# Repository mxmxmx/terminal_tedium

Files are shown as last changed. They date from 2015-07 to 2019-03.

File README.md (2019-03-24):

terminal_tedium
===============

My image

raspberry pi 2 / pi 3 / zero (W) / pi a+ / b+  eurorack stereo codec (wm8731) breakout board *

- 4x digital inputs (> 100k input impedance; threshold > 3V)
- 2x digital outputs (~ 6V )
- 6x CV inputs (100k input impedance; 12 bit, +/- 5V range)
- 2x audio outputs (10VPP, 16bit / 48kHz)
- 2x audio inputs (50k input impedance, 16bit / 48kHz)

build info, see here: https://github.com/mxmxmx/terminal_tedium/wiki

[PCBs/panels](https://pushermanproductions.com/?s=terminal&post_type=product)

## places to find Pd patches for Terminal Tedium
Here are a few places where you can find Pd patches that others have written for the Terminal Tedium:

- [Old Man Fury's Github repos](https://github.com/oldmanfury)
- [Wilsontr's Github repo](https://github.com/wilsontr/tt-patches)
- [j-p-higgins' Github repo](https://github.com/j-p-higgins/jh.tt)
- [North Coast Modular Collective's Github repo](https://github.com/NorthCoastModularCollective/Terminal-Tedium-Pd-Patches)
- [JMC64 Patches](https://github.com/JMC64/Terminal-Tedium-)

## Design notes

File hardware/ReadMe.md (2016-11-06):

# this folder contains various CAM files and design resources.

- ### the `gerbers` folder is … where the gerber files can be found.

- the remaining stuff is mostly about panels, ie layout + dimensions:

  - .fpd (for use with front panel express / schaeffer)
  - .svg and .pdf (for use with whatever)
  - .fzz is another panel design. you'll need fritzing to edit it, adjust pot-sizes, graphics, etc

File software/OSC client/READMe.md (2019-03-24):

# (primitive) OSC / UDP client

- note: as is, the client works with the wm8731 version only.

- still needs adjusting port # and IP address *manually* (in `int main(void)`)

- compile with: 

`gcc *.c -Werror -lwiringPi -std=gnu99 -O2 -g -o tedium_osc` 

- run with:

`sudo ./tedium_osc`

- adc values 0-5 are sent as an OSC bundle (range = `0 (min) - 4000 (max)`): 

`/adc0 value, /adc1 value, /adc2 value ... `

- button presses (short, long) and triggers are sent as individual OSC messages (`1` or `0`), namely:

`/trigger1 value`
`/trigger2 value`
`/trigger3 value`
`/trigger4 value`

`/button1 value`
`/button2 value`
`/button3 value`

`/button1_long value`
`/button2_long value`
`/button3_long value`

- edit main.c to customize the messages.

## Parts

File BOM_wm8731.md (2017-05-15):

# BOM for terminal tedium IO 

### resistors 0603:

| value | # | note |
| --- | ---: | --- |
| 200R | 2x | |
| 220R | 4x | filter bead; mouser # 81-BLM18BB221SN1D |
| 510R | 4x | |
|1k | 4x | |
| 4k7 | 2x | |					
| 5k6 | 2x | | 		 
| 10k | 2x | | 				
| 24k9 | 12x | |				
| 27k | 2x | | 					
| 33k | 5x | | 			
| 47k | 5x | | 
| 49k9 | 2x | (or use 47k) |
| 100k | 14x |  |			
| LED resistors | 2x | (for the 3mm LEDs) (†) |

- (†) best to use **ultrabright** LEDs, and correspondingly large resistor values (to taste) (V+ = 3.3v); for the illuminated tact switch, 200R works ok (as per BOM)

### caps 0603 (25v or better):

| value | # | note |
| --- | ---: | --- |
| 18-20p | 6x | NP0/C0G |
| 10n | 7x | NP0/C0G |	 
| 100n | 14x | MLCC | 
| 470n | 3x | MLCC |
| 1uF  | 2x | MLCC (may be 0805) |
| 10uF | 2x | MLCC (may be 0805) |

### electrolytic caps, SMD:

| value | # | note |
| --- | ---: | --- |
| 10uF | 5x | 16V or better; diameter < 5.3mm; e.g. mouser # 647-UUQ1E100MCL1GB |
| 33uF | 3x | 25V or better; diameter < 8mm |

### ICs/semis/etc:

| what | # | package | note |
| --- | ---: | --- | --- |
| WM8731 | 1 x | TSSOP-28 | mouser # 238-WM8731SEDS/V |
| MCP3208 | 1x | SOIC16 | mouser # 579-MCP3208CISL |
| TL072 | 3x | SOIC8 | see note (†) |
| MCP6002 | 1x | SOIC8 | mouser # 579-MCP6002T-I/SN |
| MCP6004 | 1x | SOIC14 | mouser # 579-MCP6004T-I/SL |
| MMBT3904 | 4x | SOT-23 | mouser # 512-MMBT3904 |
| SM5817PL-TP | 3x | SOD-123FL | mouser # 833-SM5817PL-TP |
| ADP150 | 1x | TSOT | 3v3 regulator; mouser # 584-ADP150AUJZ-3.3R7 |
| LM4040-2v5 | 1x | SOT-23 | - |
| LM4040-10v | 1x | SOT-23 | - |

- (†) two of the TL072s are in the audio path — if you’d like, use something better for the output stage.

### through-hole parts:

| what | # | package | note |
| --- | ---: | --- | --- |
| 12.288 MHz crystal | 1x | HC-49/S |  low profile |
| electrolytic capacitor, **10uF** | 2x | 2.5mm | 16V+ (for DC block / **audio** output) |
| inductance, 10uH | 1x | - | e.g. mouser # 542-78F100-RC |
| RECOM 785.0 1.0 | 1x | - | mouser # 919-R-785.0-1.0 (†) |
| 3mm LEDs | 2x | - | (use ultra-bright) |

- (†) the 500 ma version should do for models a+, b+; pi 2 needs 1.0, it looks like; as a cheaper/less efficient solution, use a 7805. if planning to power the raspberry via usb (= 5v disconnected! or no 5V regulator soldered), no such $ regulator is needed, of course.

### misc:

| what | # | note |
| --- | ---: | --- |
| jacks | 16x | thonkiconn/kobiconn |
| potentiometers | 6x | 9mm vertical, 10k**B** |
| tact switches | 2x | multimecs 5E/5G series; mouser # 642-5GTH935 |
| illum. tact switch | 1x | ditto; e.g. mouser # 642-5GTH93542 (= YELLOW) |
| caps, black | 2x | mouser # 642-1SS09-15.0, or 642-1SS09-16.0 |
| caps, transparent | 1x | mouser # 642-1IS11-15.0, or 642-1IS11-16.0 |
| 2-pin header, male | 1x | RM2.54 (+ little jumper plastic thingie to match (= the 5V power jumper)|
| raspberry GPIO socket, 2x20 | 1x | RM2.54, extra-tall female socket for RPI (†) |
| spacer/standoff (M3) | 2x | to match height of the 2x20 socket/header (c. 20mm for pi B+, pi 2, pi 3) |

- (†) or four of [these](http://www.taydaelectronics.com/connectors-sockets/stackable-headers/stackable-header-10-pins-2-54mm.html), for example, will do; if planning to use model A+ or zero, the socket doesn't have to be as tall.

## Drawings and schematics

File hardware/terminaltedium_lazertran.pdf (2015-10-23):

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

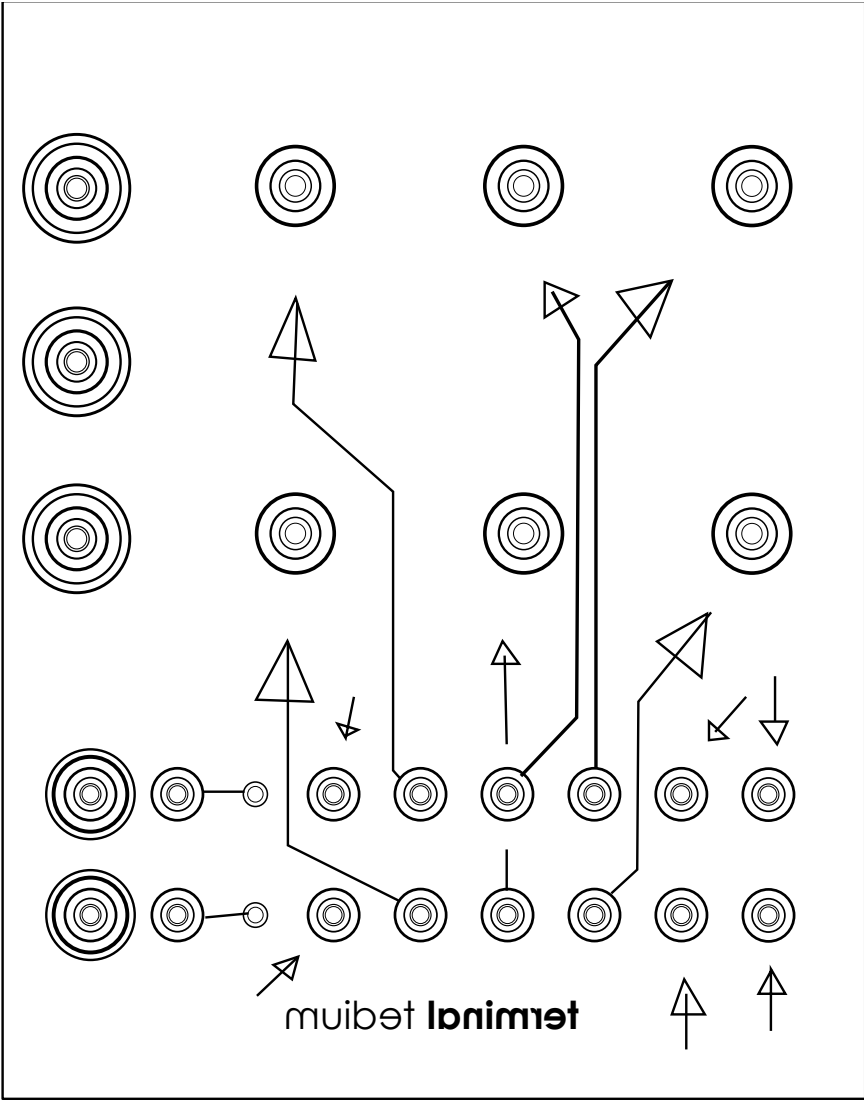
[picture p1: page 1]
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

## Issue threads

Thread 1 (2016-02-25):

RPI 2 problems with wm8731

Shibonja, 2016-02-25:
Hi,

Nice work you have done with the sound mixer. Can I ask you which version of raspbian you are using. I downloaded Raspbian Jessie (kernel version 4.1.18-v7+) and can't get my wm8731 working.
I am getting these errors in dmesg:
```bash
[    6.100440]snd-rpi-proto sound: ASoC: CPU DAI (null) not registered
[    6.100462] snd-rpi-proto sound: snd_soc_register_card() failed: -517
[    6.100963] snd-rpi-proto sound: ASoC: CPU DAI (null) not registered
[    6.100989] snd-rpi-proto sound: snd_soc_register_card() failed: -517
[    6.102795] bcm2708_i2c 3f804000.i2c: BSC1 Controller at 0x3f804000 (irq 79) (baudrate 100000)
[    6.103079] snd-rpi-proto sound: ASoC: CPU DAI (null) not registered
[    6.103091] snd-rpi-proto sound: snd_soc_register_card() failed: -517
[    6.105641] snd-rpi-proto sound: ASoC: CODEC DAI wm8731-hifi not registered
[    6.105654] snd-rpi-proto sound: snd_soc_register_card() failed: -517
```
Regards, Haris

Shibonja, 2016-02-25:
Hi, I got playback working.  But sound recording doesn't work, have you experience with sound recording.

mxmxmx, 2016-02-25:
Hi Haris,

I haven't done any nice work with the sound mixer (?), but observing [this](https://github.com/mxmxmx/terminal_tedium/wiki/DAC#3-amixer) should be enough to get the inputs working.

mxmxmx, 2016-02-25:
As this seems to be about mikroelektronika boards, not terminal tedium, I'm closing this Issue.

Closed 2016-02-25.

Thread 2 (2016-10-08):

DC Coupled Audio Output to use as CV?

bsom, 2016-10-08:
It is stated here: https://github.com/mxmxmx/terminal_tedium/wiki/wm8731
that the audio outputs are "simple inverting amplifier with ~ 4.75x gain; outputs are DC blocked".

Is there a modification/edit/hack that could be done so that the audio outs are actually able to produce something closer to DC-coupled CV?

synthbytes, 2016-10-08:
DC blocked means there is a capacitor terminating the output and will only let AC pass. To allow DC you'd remove the cap.

bsom, 2016-10-08:
I understand that, but without a schematic, it is hard for me to be sure I am removing the correct part.

mxmxmx, 2016-10-09:
... the link above comes with the relevant schematic snippet (?) --https://github.com/mxmxmx/terminal_tedium/wiki/wm8731#output-stage

or what else would you need ? fwiw, the caps in question are the through-hole ones on the top side of the board.

bsom, 2016-10-11:
Thanks for the hint about the through-hole electrolytic caps.

Closed 2016-10-11.

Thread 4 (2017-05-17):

PiCore requires wiringPi-Dev to be installed to compile Externals

bsom, 2017-05-17:
In order to compile the Externals on PiCore, wiringPi-Dev is required.  It contains the headers for wiringPi.  I don't know if this is true for 'regular' RaspPi distributions, but I needed to do it with PiCore 8.x and 9.0.

mxmxmx, 2017-05-17:
ok, thanks -- added it to the how-to (which i guess could need an update)

bsom, 2017-05-18:
I'm about to construct an additional T_T using piCore 9.0.  I'll make notes about where the instructions for piCore need updating and submit another issue with potential changes.

mxmxmx, 2017-05-18:
cool, that would be great ("could need an update" was more like a note to myself though!)

Closed 2017-05-17.

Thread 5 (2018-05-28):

Schematic files

wraybowling, 2018-05-28:
It's already noted in the hardware readmme that schematics are absent. Could be solved. I'm starting a KiCAD schematic on my fork, but consider myself by no means an expert. Help is welcome

mxmxmx, 2018-05-30:
hey
you probably can save your time ... Raffael / @seismicindustries has redrawn the board, with OLED(s) added. not entirely sure what the status is, but it's almost there, i think.

bsom, 2018-05-30:
I only see the O_c on @seismicindustries.  Has he not published it yet or are you confusing the O_c with the terminal_tedium?

mxmxmx, 2018-05-30:
not published yet

bsom, 2018-05-30:
Well, now I’m excited to see what became up with!

seismicindustries, 2018-05-30:
now published. but untested so far.
https://github.com/seismicindustries/TT

wraybowling, 2018-06-28:
@seismicindustries Firstly THANK YOU. I'm still a super beginner with electronics design and KiCAD so that was extremely useful.

Second, here's the BOM converted to Octopart https://octopart.com/bom-tool/v96smgng

Third, @mxmxmx, this is a great start to getting the hardware updated on your repo. Still think that we should do that.

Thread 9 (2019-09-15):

compatible with raspberry pi 4 B?

michaelpalumbo, 2019-09-15:
Hi there, exciting project!

Is this by any chance compatible with the newer raspberry pi model 4 B?

Thanks!

mxmxmx, 2019-09-16:
in terms of pin usage/signals, yes ("Complete compatibility with earlier Raspberry Pi products"). in terms of power requirements, pi 4 may begin stretching things a little (RECOM 785.0 1.0 = 1.0A; they recommend using 3.0A). that said, you can just power the pi 4 separately, simply remove the [jumper](https://github.com/mxmxmx/terminal_tedium/wiki/wm8731#power) to disconnect the SoC from the onboard 5V.

michaelpalumbo, 2019-09-18:
@mxmxmx well thats rad! and also kinda cool that the TT wouldn't take up a power port from my euro supply. thanks!

Closed 2019-09-18.

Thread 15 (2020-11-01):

100K Resistors quantity

RiccardoRics, 2020-11-01:
Hi there, on the BOM file are reported 14x 100K resistors, but on the REV.1 board I see 18x 100K.
Is that a typo into the BOM?

2x near the 072
4x near the MCP6002
8x near the MCP6004
4x near the GPIO 04-14-17-27

I've downloaded the gerber zip and by opening the "terminal_tedium_io_rev2016_pnp.txt" file I searched for 100K and found effectively 18x 100K resistors elements.

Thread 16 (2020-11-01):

10nF quantity

RiccardoRics, 2020-11-01:
Hi there, on the BOM file are reported 7x 10nF caps, but on the REV.1 board I see 1x 10nF and 6x 1nF.
Is that a typo into the BOM?

1x 10nF near the 072
2x 1nF near the MCP6002
4x 1nF near the MCP6004

Into the "terminal_tedium_io_rev2016_pnp.txt" file I searched for 10nF and found effectively 7x 10nF caps elements but no 1nF elements.

RiccardoRics, 2020-11-01:
Ok, got the tip on the building wiki page:

"you can follow the values indicated on the pcb. no special precautions required. except, ideally use 10nF caps (NP0) where it says 1nF (around the MCP6002s). (silkscreen fixed in revision 1.1)"

Closed 2020-11-01.

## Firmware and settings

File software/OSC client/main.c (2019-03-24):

/*
*
*   terminal tedium / OSC client (UDP)
*
*     
*   - TD: gate outputs (?); make nicer. etc (pigpio?)
*   - TD: make more userfriendly, pass IP and port as arguments, etc.
*
*
*   compile with: gcc *.c -Werror -lwiringPi -std=gnu99 -O2 -g -o tedium_osc 
*/

#define DEFAULT_SOURCE

#include <stdio.h>
#include <string.h>
#include <stdlib.h>
#include <arpa/inet.h>
#include <sys/socket.h>
#include <fcntl.h>
#include <time.h>
#include <unistd.h>
#include <sys/time.h>  

#include <wiringPi.h>
#include <wiringPiSPI.h>

#include "tinyosc.h"

const uint16_t BUFLEN = 1024;
const uint64_t NOW = 1L;
const uint32_t TIMEOUT = 1000;    // sleep (in us)
const uint32_t TIMEOUT_T = 10;    // short time out (for OSC off messages) (triggers) // 10 * TIMEOUT (us)

#define ADC_SPI_CHANNEL 1
#define ADC_SPI_SPEED 4000000
#define ADC_NUM_CHANNELS 6
#define ADC_NUM ADC_NUM_CHANNELS-1
#define RESOLUTION 4095
#define DEADBAND 2
#define SCALE 4000
#define SCALE_INV 1.0f/(float)SCALE

// GPIO : 

#define B1 23
#define B2 25
#define B3 24
#define LED 26
#define TR1 4
#define TR2 17
#define TR3 14
#define TR4 27
#define GATE1 16
#define GATE2 12

#define _MUTEX 0

void die(char *s)
{
    perror(s);
    exit(1);
}

uint16_t adc[ADC_NUM_CHANNELS]; // adc values


/*  interrupt flags etc:  */

static volatile uint8_t TR1_flag = 0;
static volatile uint8_t TR2_flag = 0;
static volatile uint8_t TR3_flag = 0;
static volatile uint8_t TR4_flag = 0;
static volatile uint8_t B1_flag  = 0;
static volatile uint8_t B2_flag  = 0;
static volatile uint8_t B3_flag  = 0;

void Interrupt_TR1 (void) { TR1_flag = 1; }
void Interrupt_TR2 (void) { TR2_flag = 1; }
void Interrupt_TR3 (void) { TR3_flag = 1; }
void Interrupt_TR4 (void) { TR4_flag = 1; }
void Interrupt_B1  (void) { B1_flag  = 1; }
void Interrupt_B2  (void) { B2_flag  = 1; }
void Interrupt_B3  (void) { B3_flag  = 1; }

// flags and counters for on/off messages:

uint8_t TR1_OFF = 0; 
uint8_t TR2_OFF = 0; 
uint8_t TR3_OFF = 0; 
uint8_t TR4_OFF = 0; 
uint16_t _wait_TR1, _wait_TR2, _wait_TR3, _wait_TR4; 

/* 

mcp3208 : return 1 if we need to send OSC, 0 otherwise

*/


uint16_t readADC(int _channel, uint16_t *adc_val){ 

      uint8_t spi_data[3];
      uint16_t result, tmp = *(adc_val + _channel); // previous.

      spi_data[0] = 0x06 | (_channel>>2) & 0x01;    // single ended
      spi_data[1] = _channel<<6;
      spi_data[2] = 0x00;

      wiringPiSPIDataRW(ADC_SPI_CHANNEL, spi_data, 3);

      // invert + limit result: 
      result = SCALE - (((spi_data[1] & 0x0f) << 8) | spi_data[2]);
      result = result > RESOLUTION ? 0 : result;  
      
      if ( (result - tmp) > DEADBAND || (tmp - result) > DEADBAND ) { 
        *(adc_val + _channel) = result ;
        return 1;
      }
      else {
        *(adc_val + _channel)  = tmp;
        return 0;
      }
}


///  buttons: 


enum button_states 
{
  OK,
  PRESSED,
  SHORT_PRESS,
  LONG_PRESS,
  SEND_OFF_MSG,
  SEND_OFF_MSG_L
};

typedef struct buttons
{
   uint8_t _pin;
   uint8_t _state;
   uint8_t _OSC_state;
   uint16_t _cnt;

} buttons;

buttons *button1, *button2, *button3;


void init_buttons() {

  button1 = (buttons*)malloc(sizeof(buttons));
  button2 = (buttons*)malloc(sizeof(buttons));
  button3 = (buttons*)malloc(sizeof(buttons));

  button1->_pin = B1;
  button1->_state = OK;
  button1->_OSC_state = OK;
  button1->_cnt = 0;

  button2->_pin = B2;
  button2->_state = OK;
  button2->_OSC_state = OK;
  button2->_cnt = 0;

  button3->_pin = B3;
  button3->_state = OK;
  button3->_OSC_state = OK;
  button3->_cnt = 0;

}

void check_buttons(struct buttons* _b, int time_out)
{

  if (_b->_state == PRESSED) {

        uint8_t _s = digitalRead(_b->_pin);
        if (!_s) _b->_cnt++;
        else if (_s && _b->_cnt < time_out)  _b->_state = SHORT_PRESS;
        else if (_s && _b->_cnt >= time_out) _b->_state = LONG_PRESS;

  }
  else if (_b->_state > PRESSED) { 

        piLock (_MUTEX);
          _b->_OSC_state = _b->_state;
        piUnlock (_MUTEX);  
        // reset
        _b->_state = OK;
        _b->_cnt = 0;
  }
}

///////////////////

PI_THREAD (handle_GPIO)
{

  uint16_t time_out = 125; // wait until longpress
  uint32_t _sleep = TIMEOUT*6;

  init_buttons();

  while(1) {

     usleep(_sleep);

     if (B1_flag && button1->_state == OK) { 

        B1_flag =  0;
        button1->_state = PRESSED;
     }

     if (B2_flag && button2->_state == OK) { 

        B2_flag =  0;
        button2->_state = PRESSED;
     }

     if (B3_flag && button3->_state == OK) { 

        B3_flag =  0;
        button3->_state = PRESSED;
     }

     check_buttons(button1, time_out);
     check_buttons(button2, time_out);
     check_buttons(button3, time_out);
  }
}

/* --------------------------------------------------------- */

int main(void)
{
    struct sockaddr_in _serv;
    int s, i, slen = sizeof(_serv);
    char buf[BUFLEN];
    int port = 9000;
    char *ip = "127.0.0.1"; 

    memset(adc, 0, ADC_NUM_CHANNELS);

    // open socket : 
    if ((s=socket(AF_INET, SOCK_DGRAM, IPPROTO_UDP)) == -1) die("socket");
    
    memset((char *) &_serv, 0, sizeof(_serv));
    _serv.sin_family = AF_INET;
    _serv.sin_port = htons(port);
    _serv.sin_addr.s_addr =  inet_addr(ip);

    // OSC bundle
    tosc_bundle bundle;

    // setup SPI
    wiringPiSetupGpio();
    wiringPiSPISetup(ADC_SPI_CHANNEL, ADC_SPI_SPEED);

    // pull ups:
    pinMode(B1, INPUT);
    pullUpDnControl(B1, PUD_UP);
    pinMode(B2, INPUT);
    pullUpDnControl(B2, PUD_UP);
    pinMode(B3, INPUT);
    pullUpDnControl(B3, PUD_UP);

    pinMode(TR1, INPUT);
    pullUpDnControl(TR1, PUD_UP);
    pinMode(TR2, INPUT);
    pullUpDnControl(TR2, PUD_UP);
    pinMode(TR3, INPUT);
    pullUpDnControl(TR3, PUD_UP);
    pinMode(TR4, INPUT);
    pullUpDnControl(TR4, PUD_UP);

    // LED + gate outputs (??) (what should those do?)
    pinMode(LED, OUTPUT);
    pinMode(GATE1, OUTPUT);
    pinMode(GATE2, OUTPUT);

    // interrupt, trigger inputs: 
    wiringPiISR (TR1, INT_EDGE_FALLING, &Interrupt_TR1) ;
    wiringPiISR (TR2, INT_EDGE_FALLING, &Interrupt_TR2) ;
    wiringPiISR (TR3, INT_EDGE_FALLING, &Interrupt_TR3) ;
    wiringPiISR (TR4, INT_EDGE_FALLING, &Interrupt_TR4) ;
    
    // interrupt, buttons: 
    wiringPiISR (B1, INT_EDGE_FALLING, &Interrupt_B1)  ;
    wiringPiISR (B2, INT_EDGE_FALLING, &Interrupt_B2)  ; 
    wiringPiISR (B3, INT_EDGE_FALLING, &Interrupt_B3)  ; 

    // flags
    int _cnt = 0, _send = 0, toggle = 0;

    // thread to handle buttons
    piThreadCreate (handle_GPIO);

    // main action is happening here (..)
     while(1)
    {
            usleep(TIMEOUT);
            // get adc value
            _send += readADC(_cnt, adc);
            // do we need to send an OSC bundle? 
            if (_cnt == ADC_NUM && _send) {
              
                  // construct OSC bundle:
                  tosc_writeBundle(&bundle, NOW, buf, BUFLEN);
                  tosc_writeNextMessage(&bundle, "/adc0", "f", (float)adc[0] * SCALE_INV);
                  tosc_writeNextMessage(&bundle, "/adc1", "f", (float)adc[1] * SCALE_INV);
                  tosc_writeNextMessage(&bundle, "/adc2", "f", (float)adc[2] * SCALE_INV);
                  tosc_writeNextMessage(&bundle, "/adc3", "f", (float)adc[3] * SCALE_INV);
                  tosc_writeNextMessage(&bundle, "/adc4", "f", (float)adc[4] * SCALE_INV);
                  tosc_writeNextMessage(&bundle, "/adc5", "f", (float)adc[5] * SCALE_INV);
                  // ... and send bundle:
                  int len = tosc_getBundleLength(&bundle);

                  if (sendto(s, buf, len, 0 , (struct sockaddr *) &_serv, slen)==-1) die("sendto()");
                  // reset flag
                  _send = 0;
            }
            // increment adc cycle counter
            _cnt = _cnt++ >= ADC_NUM ? 0x0 : _cnt; // 0x5 = ADC_NUM_CHANNELS-1

            // buttons ?

            switch(button1->_OSC_state) {

              case OK:
                break;
              case SHORT_PRESS: {

                int len = tosc_writeMessage(buf, sizeof(buf), "/button1", "i", 1);
                  // send message:
                  sendto(s, buf, len, 0, (struct sockaddr *) &_serv, slen);
                  piLock (_MUTEX);
                    button1->_OSC_state = SEND_OFF_MSG;
                  piUnlock (_MUTEX);
                break;
              }

              case LONG_PRESS: {
                int len = tosc_writeMessage(buf, sizeof(buf), "/button1_long", "i", 1);
                  // send message:
                  sendto(s, buf, len, 0, (struct sockaddr *) &_serv, slen);
                  piLock (_MUTEX);
                    button1->_OSC_state = SEND_OFF_MSG_L;
                  piUnlock (_MUTEX);
                break;
              }
              case SEND_OFF_MSG: {
                int len = tosc_writeMessage(buf, sizeof(buf), "/button1", "i", 0);
                  // send message:
                  sendto(s, buf, len, 0, (struct sockaddr *) &_serv, slen);
                  piLock (_MUTEX);
                    button1->_OSC_state = OK;
                  piUnlock (_MUTEX);
                break;
              }
              case SEND_OFF_MSG_L: {
                int len = tosc_writeMessage(buf, sizeof(buf), "/button1_long", "i", 0);
                  // send message:
                  sendto(s, buf, len, 0, (struct sockaddr *) &_serv, slen);		
                  piLock (_MUTEX);
                    button1->_OSC_state = OK;
                  piUnlock (_MUTEX);
                break;
              }
              default: break;
          }  

          switch(button2->_OSC_state) {

              case OK:
                break;
              case SHORT_PRESS: {
                int len = tosc_writeMessage(buf, sizeof(buf), "/button2", "i", 1);
                  // send message:
                  sendto(s, buf, len, 0, (struct sockaddr *) &_serv, slen);
                  piLock (_MUTEX);
                    button2->_OSC_state = SEND_OFF_MSG;
                  piUnlock (_MUTEX);
                break;
              }
              case LONG_PRESS: {

                int len = tosc_writeMessage(buf, sizeof(buf), "/button2_long", "i", 1);
                  // send message:
                  sendto(s, buf, len, 0, (struct sockaddr *) &_serv, slen);
                  piLock (_MUTEX);
                    button2->_OSC_state = SEND_OFF_MSG_L;
                  piUnlock (_MUTEX);
                break;
              }
              case SEND_OFF_MSG: {

                int len = tosc_writeMessage(buf, sizeof(buf), "/button2", "i", 0);
                  // send message:
                  sendto(s, buf, len, 0, (struct sockaddr *) &_serv, slen);
                  piLock (_MUTEX);
                    button2->_OSC_state = OK;
                  piUnlock (_MUTEX);
                break;
              }
              case SEND_OFF_MSG_L: {

                int len = tosc_writeMessage(buf, sizeof(buf), "/button2_long", "i", 0);
                  // send message:
                  sendto(s, buf, len, 0, (struct sockaddr *) &_serv, slen);
                  piLock (_MUTEX);
                    button2->_OSC_state = OK;
                  piUnlock (_MUTEX);
                break;
              }
              default: break;
          } 

          switch(button3->_OSC_state) {

              case OK:
                break;
              case SHORT_PRESS: {
                int len = tosc_writeMessage(buf, sizeof(buf), "/button3", "i", 1);
                  // send message:
                  sendto(s, buf, len, 0, (struct sockaddr *) &_serv, slen);
                  piLock (_MUTEX);
                    button3->_OSC_state = SEND_OFF_MSG;
                  piUnlock (_MUTEX);
                  toggle = ~toggle & 1u;
                  digitalWrite(LED, toggle);
                break;
              }
              case LONG_PRESS: {

                int len = tosc_writeMessage(buf, sizeof(buf), "/button3_long", "i", 1);
                  // send message:
                  sendto(s, buf, len, 0, (struct sockaddr *) &_serv, slen);
                  piLock (_MUTEX);
                    button3->_OSC_state = SEND_OFF_MSG_L;
                  piUnlock (_MUTEX);
                  toggle = ~toggle & 1u;
                  digitalWrite(LED, toggle);
                break;
              }
              case SEND_OFF_MSG: {

                int len = tosc_writeMessage(buf, sizeof(buf), "/button3", "i", 0);
                  // send message:
                  sendto(s, buf, len, 0, (struct sockaddr *) &_serv, slen);
                  piLock (_MUTEX);
                    button3->_OSC_state = OK;
                  piUnlock (_MUTEX);
                break;
              }
              case SEND_OFF_MSG_L: {

                int len = tosc_writeMessage(buf, sizeof(buf), "/button3_long", "i", 0);
                  // send message:
                  sendto(s, buf, len, 0, (struct sockaddr *) &_serv, slen);
                  piLock (_MUTEX);
                    button3->_OSC_state = OK;
                  piUnlock (_MUTEX);
                break;
              }
              default: break;
          } 

          // handle trig inputs:

            if (TR1_flag && !TR1_OFF) { 

                    TR1_flag =  0;
                    int len = tosc_writeMessage(buf, sizeof(buf), "/trigger1", "i", 1);
                    // send message:
                    if (sendto(s, buf, len, 0, (struct sockaddr *) &_serv, slen)) TR1_OFF = 1;
                    _wait_TR1 = 0;
            }

            if (TR2_flag && !TR2_OFF) { 

                    TR2_flag =  0;
                    int len = tosc_writeMessage(buf, sizeof(buf), "/trigger2", "i", 1);
                    // send message:
                    if (sendto(s, buf, len, 0, (struct sockaddr *) &_serv, slen)) TR2_OFF = 1;
                    _wait_TR2 = 0;
            }

            if (TR3_flag && !TR3_OFF) { 

                    TR3_flag =  0;
                    int len = tosc_writeMessage(buf, sizeof(buf), "/trigger3", "i", 1);
                    // send message:
                    if (sendto(s, buf, len, 0, (struct sockaddr *) &_serv, slen)) TR3_OFF = 1;
                    _wait_TR3 = 0;
            }

            if (TR4_flag && !TR4_OFF) { 

                    TR4_flag =  0;
                    int len = tosc_writeMessage(buf, sizeof(buf), "/trigger4", "i", 1);
                    // send message:
                    if (sendto(s, buf, len, 0, (struct sockaddr *) &_serv, slen)) TR4_OFF = 1;
                    _wait_TR4 = 0;
            }

            // turn off gate1
            if (TR1_OFF && _wait_TR1 < TIMEOUT_T) _wait_TR1++;
            else if (TR1_OFF && _wait_TR1 >= TIMEOUT_T) {
                    // reset
                    TR1_OFF = _wait_TR1 = 0;
                    int len = tosc_writeMessage(buf, sizeof(buf), "/trigger1", "i", 0);
                    sendto(s, buf, len, 0, (struct sockaddr *) &_serv, slen);
            } 
            // turn off gate2
            if (TR2_OFF && _wait_TR2 < TIMEOUT_T) _wait_TR2++;
            else if (TR2_OFF && _wait_TR2 >= TIMEOUT_T) {
                    // reset
                    TR2_OFF = _wait_TR2 = 0;
                    int len = tosc_writeMessage(buf, sizeof(buf), "/trigger2", "i", 0);
                    sendto(s, buf, len, 0, (struct sockaddr *) &_serv, slen);
            } 
            // turn off gate3
            if (TR3_OFF && _wait_TR3 < TIMEOUT_T) _wait_TR3++;
            else if (TR3_OFF && _wait_TR3 >= TIMEOUT_T) {
                    // reset
                    TR3_OFF = _wait_TR3 = 0;
                    int len = tosc_writeMessage(buf, sizeof(buf), "/trigger3", "i", 0);
                    sendto(s, buf, len, 0, (struct sockaddr *) &_serv, slen);
            } 
            // turn off gate4
            if (TR4_OFF && _wait_TR4 < TIMEOUT_T) _wait_TR4++;
            else if (TR4_OFF && _wait_TR4 >= TIMEOUT_T) {
                    // reset
                    TR4_OFF = _wait_TR4 = 0;
                    int len = tosc_writeMessage(buf, sizeof(buf), "/trigger4", "i", 0);
                    sendto(s, buf, len, 0, (struct sockaddr *) &_serv, slen);
            }
    }
    close(s);
    return 0;
}
// end

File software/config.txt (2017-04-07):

# For more options and information see
# http://www.raspberrypi.org/documentation/configuration/config-txt.md
# Some settings may impact device functionality. See link above for details

# uncomment if you get no picture on HDMI for a default "safe" mode
#hdmi_safe=1

# uncomment this if your display has a black border of unused pixels visible
# and your display can output without overscan
#disable_overscan=1

# uncomment the following to adjust overscan. Use positive numbers if console
# goes off screen, and negative if there is too much border
#overscan_left=16
#overscan_right=16
#overscan_top=16
#overscan_bottom=16

# uncomment to force a console size. By default it will be display's size minus
# overscan.
#framebuffer_width=1280
#framebuffer_height=720

# uncomment if hdmi display is not detected and composite is being output
#hdmi_force_hotplug=1

# uncomment to force a specific HDMI mode (this will force VGA)
#hdmi_group=1
#hdmi_mode=1

# uncomment to force a HDMI mode rather than DVI. This can make audio work in
# DMT (computer monitor) modes
#hdmi_drive=2

# uncomment to increase signal to HDMI, if you have interference, blanking, or
# no display
#config_hdmi_boost=4

# uncomment for composite PAL
#sdtv_mode=2

#uncomment to overclock the arm. 700 MHz is the default.
#arm_freq=1000

# Uncomment some or all of these to enable the optional hardware interfaces
#dtparam=i2c_arm=on
#dtparam=i2s=on
#dtparam=spi=on

# Uncomment this to enable the lirc-rpi module
#dtoverlay=lirc-rpi

# Additional overlays and parameters are documented /boot/overlays/README

# Enable audio 

dtparam=audio=off
gpu_mem=16
dtparam=i2c_arm=on
dtparam=spi=on
dtparam=i2s=on
dtoverlay=i2s-mmap
dtoverlay=rpi-proto

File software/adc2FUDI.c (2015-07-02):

#include <stdio.h>
#include <stdint.h>
#include <stdlib.h>
#include <string.h>
#include <time.h>

#include <sys/socket.h> 
#include <arpa/inet.h>  
#include <netinet/tcp.h>
#include <unistd.h>     
#include <sys/time.h>

#include <math.h>
#include <wiringPi.h>
#include <wiringPiSPI.h>


#define ADC_SPI_CHANNEL 1
#define ADC_SPI_SPEED 1000000
#define ADC_NUM_CHANNELS 8
#define RESOLUTION 4095 // 1023 if using MCP3008; 4095 if using MCP3208
#define DEADBAND 2

void die(char *errorMessage)
{
  perror(errorMessage);
  exit(1);
}

// interrupt things

/*
static volatile uint8_t TR1_flag = 0;
static volatile uint8_t TR2_flag = 0;
static volatile uint8_t TR3_flag = 0;
static volatile uint8_t TR4_flag = 0;
static volatile uint8_t B1_flag  = 0;
static volatile uint8_t B2_flag  = 0;
static volatile uint8_t B3_flag  = 0;

void Interrupt_TR1 (void) { TR1_flag = 1; }
void Interrupt_TR2 (void) { TR2_flag = 1; }
void Interrupt_TR3 (void) { TR3_flag = 1; }
void Interrupt_TR4 (void) { TR4_flag = 1; }
void Interrupt_B1  (void) { B1_flag  = 1; }
void Interrupt_B2  (void) { B2_flag  = 1; }
void Interrupt_B3  (void) { B3_flag  = 1; }


// FUDI messages for triggers and buttons 
const char FUDI1[5] = {'8', '\t', '1', ';', '\0'};
const char FUDI2[5] = {'9', '\t', '1', ';', '\0'};
const char FUDI3[6] = {'1', '0', '\t', '1', ';', '\0'};
const char FUDI4[6] = {'1', '1', '\t', '1', ';', '\0'};
const char FUDI5[6] = {'1', '2', '\t', '1', ';', '\0'};
const char FUDI6[6] = {'1', '3', '\t', '1', ';', '\0'};
const char FUDI7[6] = {'1', '4', '\t', '1', ';', '\0'};
*/

uint8_t SENDMSG;

// ADC :

uint16_t adc[8] = {0, 0, 0, 0, 0, 0, 0, 0}; //  store prev.
uint8_t  map_adc[8] = {5, 2, 7, 6, 3, 0, 1, 4}; // map to panel [1 - 2 - 3; 4 - 5 - 6; 7, 8]

uint16_t readADC(int _channel){ // 12 bit

	uint8_t spi_data[3];
	uint8_t input_mode = 1; // single ended = 1, differential = 0
	uint16_t result, tmp;

	spi_data[0] = 0x04; // start flag
	spi_data[0] |= (input_mode<<1); // shift input_mode
	spi_data[0] |= (_channel>>2) & 0x01; // add msb of channel in our first command byte

	spi_data[1] = _channel<<6;
	spi_data[2] = 0x00;

	wiringPiSPIDataRW(ADC_SPI_CHANNEL, spi_data, 3);
	result = (spi_data[1] & 0x0f)<<8 | spi_data[2];
        tmp = adc[_channel]; // prev.
	if ( (result - tmp) > DEADBAND || (tmp - result) > DEADBAND ) { tmp = result ; SENDMSG = 1; }
        adc[_channel] = tmp;
	return tmp;
}

uint16_t readADC_10bit(int _channel){ // if using mcp3008

	uint8_t spi_data[3];
	uint16_t result, tmp;

	spi_data[0] = 0x01; // start flag
	spi_data[1] = (_channel + 8) << 4;
	spi_data[2] = 0x00;

	wiringPiSPIDataRW(ADC_SPI_CHANNEL, spi_data, 3);

	result = (spi_data[1] & 3)<<8 | spi_data[2];
        tmp = adc[_channel]; // prev.
        if ( (result - tmp) > DEADBAND || (tmp - result) > DEADBAND ) tmp = result ;
        adc[_channel] = tmp;
	return tmp;
}


int main(int argc, char *argv[]){
      
	int sock;                        /* Socket descriptor */
    	struct sockaddr_in echoServAddr; /* Echo server address */
    	unsigned short echoServPort;     /* Echo server port */
    	char *servIP;                    /* Server IP address (dotted quad) */
    	int rate;                        /* rate (time between each send) */
     	int value = 1;
 
	uint32_t adc_counter  = 0;
	uint8_t  adc_counter2 = 0;

    	if (argc != 4)    /*  correct number of arguments ? */
    	{
      		 fprintf(stderr, "Usage: %s <Server IP> <Server Port> <rate>\n", argv[0]);
       		 exit(1);
    	}

   	servIP = argv[1];              /* server IP address */
   	echoServPort = atoi(argv[2]);  /* server port */
    	rate = atoi(argv[3]);          /* time between each send (in milliseconds (not quite)) */

	rate *= 3000; /*  counter threshold */

    	if ((sock = socket(PF_INET, SOCK_STREAM, IPPROTO_TCP)) < 0)
        	die("socket() failed");

    	memset(&echoServAddr, 0, sizeof(echoServAddr));     /* Zero out structure */
    	echoServAddr.sin_family      = AF_INET;             /* Internet address family */
    	echoServAddr.sin_addr.s_addr = inet_addr(servIP);   /* Server IP address */
    	echoServAddr.sin_port        = htons(echoServPort); /* Server port */
	
	
    	/* connection to the echo server */
    	if (connect(sock, (struct sockaddr *) &echoServAddr, sizeof(echoServAddr)) < 0)
        die("connect() failed");
	

    	if (setsockopt(sock, IPPROTO_TCP, TCP_NODELAY, (char *)&value, sizeof(int)) < 0)
      	die("TCP_NODELAY failed");

    	
	wiringPiSetupGpio();
	wiringPiSPISetup(ADC_SPI_CHANNEL, ADC_SPI_SPEED);

   /*
	wiringPiISR (4,  INT_EDGE_FALLING, &Interrupt_TR1) ;
  	wiringPiISR (17, INT_EDGE_FALLING, &Interrupt_TR2) ;
  	wiringPiISR (2,  INT_EDGE_FALLING, &Interrupt_TR3) ;
  	wiringPiISR (3,  INT_EDGE_FALLING, &Interrupt_TR4) ;
  	wiringPiISR (23, INT_EDGE_FALLING, &Interrupt_B1)  ;
	wiringPiISR (25, INT_EDGE_FALLING, &Interrupt_B2)  ; 
	wiringPiISR (24, INT_EDGE_FALLING, &Interrupt_B3)  ; 
   */	

	for(;;){

		// digital inputs: interrupt?
       /*
		if (TR1_flag) { 
			TR1_flag = 0;
			send(sock, FUDI1, 4, 0); // strlen(FUDI2) = 4
		}
		if (TR2_flag) { 
			TR2_flag = 0;	
			send(sock, FUDI2, 4, 0); // strlen(FUDI2) = 4
		}
		if (TR3_flag) { 
			TR3_flag = 0;
			send(sock, FUDI3, 5, 0); // strlen(FUDI3) = 5
		}
		if (TR4_flag) { 
			TR4_flag = 0;
			send(sock, FUDI4, 5, 0); // strlen(FUDI4) = 5
		}
		if ( B1_flag) { 
			B1_flag =  0;
			send(sock, FUDI5, 5, 0); // strlen(FUDI5) = 5
		}
		if ( B2_flag) {  
			B2_flag =  0;
			send(sock, FUDI6, 5, 0); // strlen(FUDI6) = 5
		}
		if ( B3_flag) {  
			B3_flag =  0;
			send(sock, FUDI7, 5, 0); // strlen(FUDI7) = 5
		}
        */
                /// ADC: 
	     
		adc_counter++;
				
		if (adc_counter > rate){
                        
			adc_counter = 0; // reset counter
			adc_counter2++;  // incr  counter #2
			if (adc_counter2 >= ADC_NUM_CHANNELS) adc_counter2 = 0; 
                        uint8_t *adc_ptr = map_adc;
			adc_ptr += adc_counter2; // -> map to panel
			int16_t val = 0;
			uint8_t msgLength;
			char *ADC_FUDI;

			val = RESOLUTION - readADC(adc_counter2);
			
			if (SENDMSG) {
				if (val > 999)      msgLength = 8; 
				else if (val > 99)  msgLength = 7; 
				else if (val > 9)   msgLength = 6; 
				else 		      	msgLength = 5; 
				// format FUDI msg: { id, whitespace, val, semicolon, /0 }
				ADC_FUDI = (char *) malloc(msgLength); 
				snprintf(ADC_FUDI+2, msgLength, "%d", val);
				ADC_FUDI[0] = (char)(0x30+*adc_ptr); // + ascii offset
				ADC_FUDI[1] = ' ';
				ADC_FUDI[msgLength-2] = ';';
			
				send(sock, ADC_FUDI, strlen(ADC_FUDI), 0); 
			}
			SENDMSG = 0;
			// if (i == 5) { printf("%d \n", adc[i]);} 				
		}

	
       		
	}
}

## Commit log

2014-09-21 terminal tedium
    eurorack DAC for raspberry / odroid w
2014-09-28 BOM
    BOM
2014-12-21 teensy adapter
2015-07-01 spi text
2015-12-04 silkscreen pdf
2016-02-14 simplify BOM
2016-03-14 wiringPi hack
2016-11-06 gerbers, silkscreen
2017-03-04 [DELETE] wiringPi
2017-04-07 [config] don't overclock ...
    [config.txt]
2017-06-25 [ext] switch
2017-06-25 [ext] make switch print ticks rather than 1/2
2017-06-27 [ext] add switch object
2019-08-18 Add alternate mirror for wiringPi
    Build breaks when drogon.net is temporarily unavailable:
    git.drogon.net is temporarily unavailable. Please look for alternatives for wiringPi, etc. -Gordon
